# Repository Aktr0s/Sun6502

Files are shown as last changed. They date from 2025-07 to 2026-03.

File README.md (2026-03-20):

# Sun6502 Hobby Computer

## My first try at electonics. Wish me luck.

# Memory Map:

| Address Range | Size | Description |
|---|---|---|
| `$0000-$7FFF` | 32KB | RAM |
| `$8000-$83FF` | 1KB | VIA #1 |
| `$8400-$87FF` | 1KB | UART |
| `$8800-$8BFF` | 1KB | VIA #2 |
| `$8C00-$8FFF` | 1KB | Unused |
| `$9000-$BFFF` | 12KB | Expansion Port |
| `$C000-$FFFF` | 16KB | ROM |

> **Total:** 64KB

> **If you have a previous version of the board notice that UART and VIA #2 addresses are swaped around.**

## More Info:
While VIA's and UART have 1KB they only use first needed bits.

VIA#2 Port (Expansion) does not have CE/ signal but Bus Expansion Port does.

It should be compatible with Ben's Breadboard 6502 but you **HAVE** to change memory adressess since the memory map is different as well as elements connected to VIA

### The project took inspiration from:
* Ben Eater Breadboard 6502 Computer
* PE6502 by Putnam Electronics

> [!NOTE]
> This project has been tested and is confirmed to work.

> [!CAUTION]
> Do NOT use 74LS series TTL chips. It messes up logic and memory.
> Use 74HC series CMOS chips! If somewhere on PCB or schematic there is a mention of TTL chips, ignore them and use CMOS chips!

## Software:

Software for this computer is based on 
* [msbasic](https://github.com/mist64/msbasic), licensed under the 2-clause BSD license.

* As well as it's modified version by [Ben Eater](https://github.com/beneater/msbasic).

Original README files are in "msbasic_for_sun6502" folder.

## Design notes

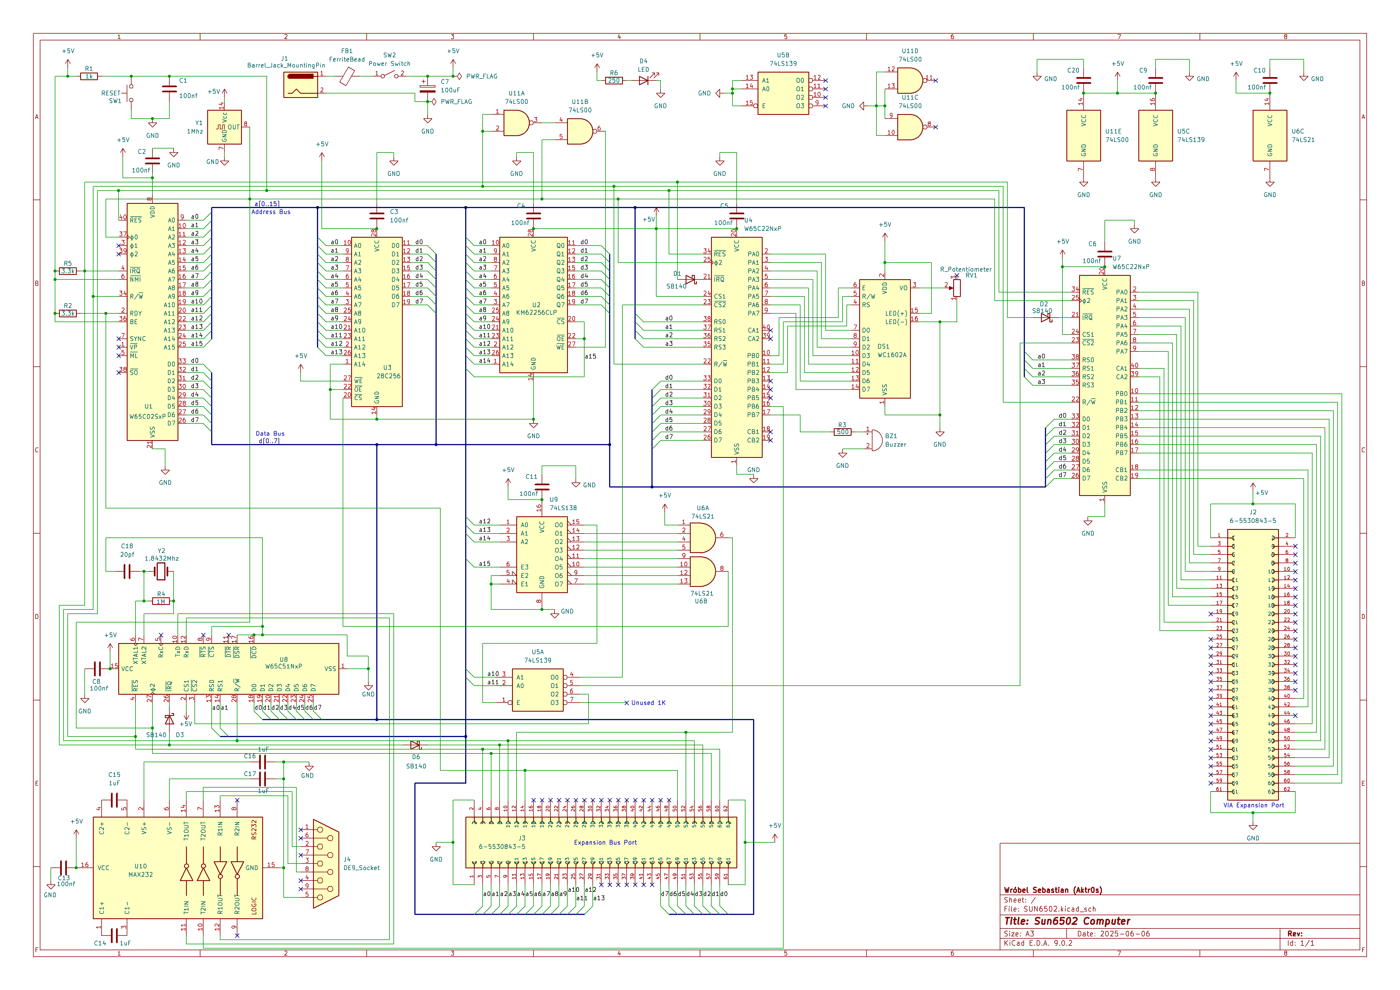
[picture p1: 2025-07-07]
schematic.png

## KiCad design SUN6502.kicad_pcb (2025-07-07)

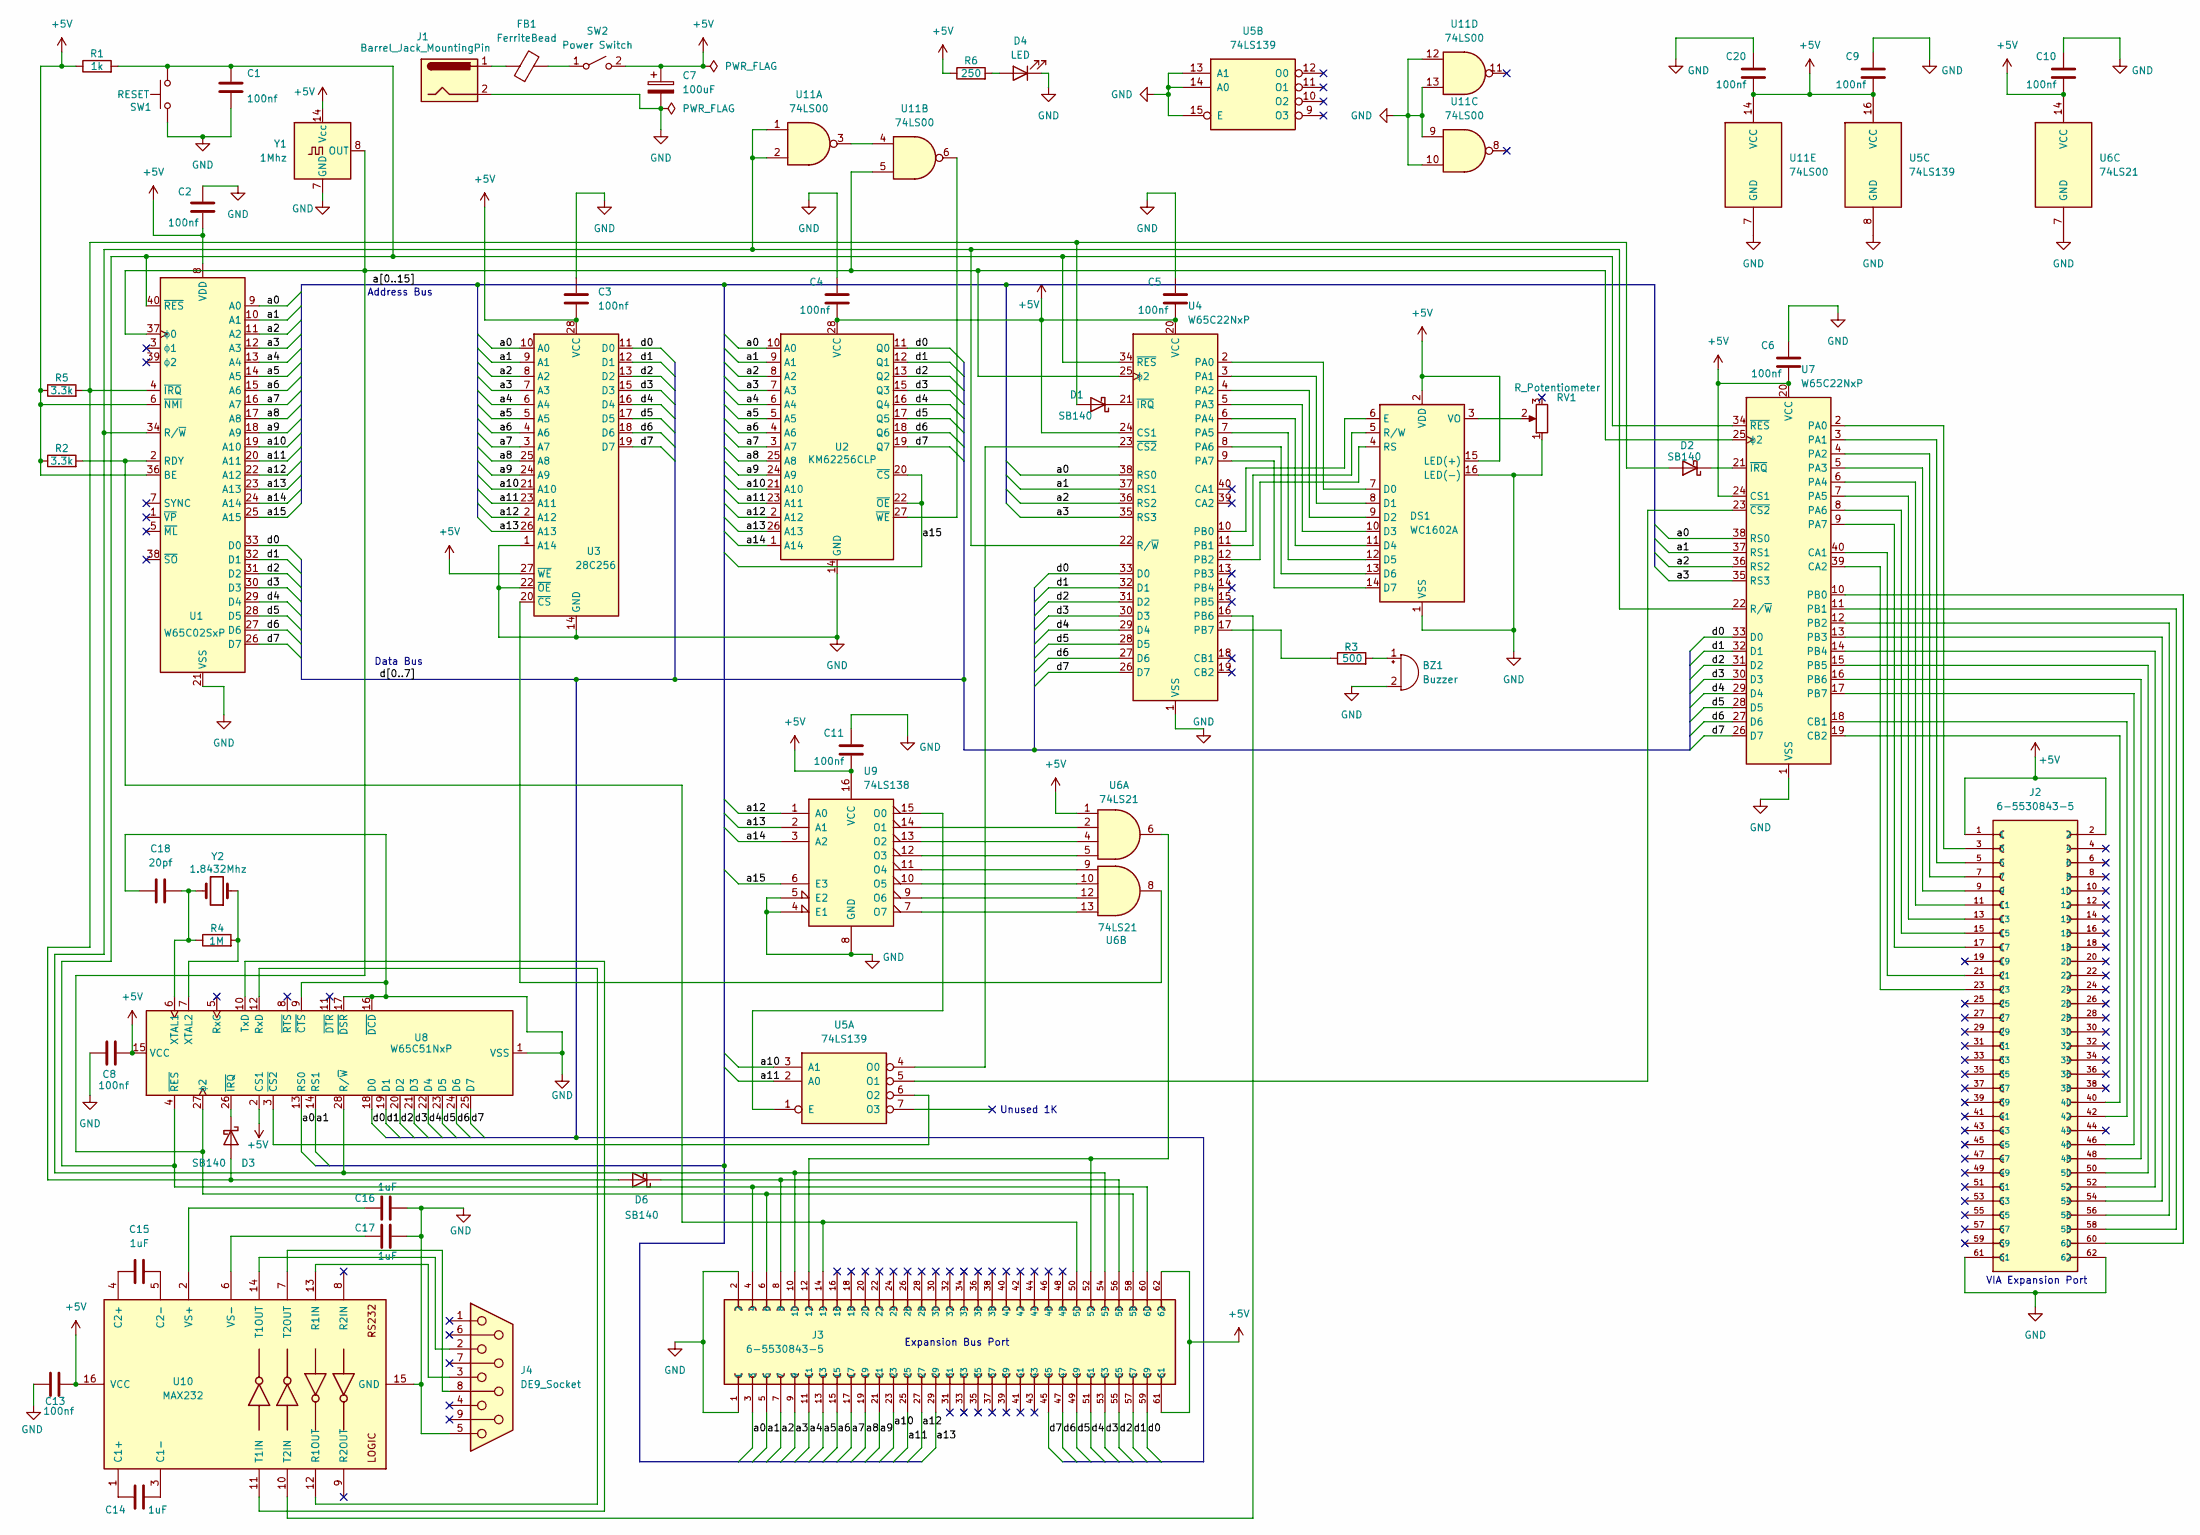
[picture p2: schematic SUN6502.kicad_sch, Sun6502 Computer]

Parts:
BZ1: Buzzer; Buzzer_TDK_PS1240P02BT_D12.2mm_H6.5mm
C1, C2, C3, C4, C5, C6, C8, C9, C10, C11, C13: 100nf; C_Disc_D5.0mm_W2.5mm_P5.00mm
C7: 100uF; CP_Radial_D6.3mm_P2.50mm
C14, C15, C16, C17: 1uF; C_Disc_D5.0mm_W2.5mm_P5.00mm
C18: 20pf; C_Disc_D5.0mm_W2.5mm_P5.00mm
C20: 100nf; C_Disc_D4.7mm_W2.5mm_P5.00mm
D1, D2, D3, D6: SB140; D_DO-41_SOD81_P10.16mm_Horizontal
D4: LED; LED_D5.0mm
DS1: WC1602A
FB1: FerriteBead; LairdTech_28C0236-0JW-10
J1: Barrel_Jack_MountingPin; BarrelJack_Horizontal
J2, J3: 6-5530843-5; TE_6-5530843-5
J4: DE9_Socket; DSUB-9_Socket_Horizontal_P2.77x2.84mm_EdgePinOffset7.70mm_H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
R1: 1k; R_Axial_DIN0207_L6.3mm_D2.5mm_P15.24mm_Horizontal
R2, R5: 3.3k; R_Axial_DIN0207_L6.3mm_D2.5mm_P15.24mm_Horizontal
R3: 500; R_Axial_DIN0207_L6.3mm_D2.5mm_P15.24mm_Horizontal
R4: 1M; R_Axial_DIN0207_L6.3mm_D2.5mm_P15.24mm_Horizontal
R6: 250; R_Axial_DIN0207_L6.3mm_D2.5mm_P10.16mm_Horizontal
RV1: R_Potentiometer; Potentiometer_Alps_RK09K_Single_Vertical
SW1: RESET; SW_PUSH_6mm_H5mm
SW2: Power Switch; 2MS6T1B3M2QES
U1: W65C02SxP; DIP-40_W15.24mm_Socket_LongPads
U2: KM62256CLP; DIP-28_W15.24mm_Socket_LongPads
U3: 28C256; DIP_Socket-28_W11.9_W12.7_W15.24_W17.78_W18.5_3M_228-1277-0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
U4, U7: W65C22NxP; DIP-40_W15.24mm_Socket_LongPads
U5: 74LS139; DIP-16_W7.62mm_Socket_LongPads
U6: 74LS21; DIP-14_W7.62mm_Socket_LongPads
U8: W65C51NxP; DIP-28_W15.24mm_Socket_LongPads
U9: 74LS138; DIP-16_W7.62mm_Socket_LongPads
U10: MAX232; DIP-16_W7.62mm_Socket_LongPads
U11: 74LS00; DIP-14_W7.62mm_Socket_LongPads
Y1: 1Mhz; Oscillator_DIP-14
Y2: 1.8432Mhz; Crystal_HC49-U_Vertical

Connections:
+5V: C2.2, C3.2, C4.2, C5.2, C6.2, C7.1, C8.2, C9.2, C10.2, C11.2, C13.2, C20.2, DS1.2 (VDD), DS1.15 (LED(+)), J2.1, J2.2, J3.61, J3.62, R1.1, R2.1, R5.1, R6.1, SW2.2 (B), U1.6 (~NMI), U1.8 (VDD), U1.36 (BE), U2.28 (VCC), U3.27 (~WE), U3.28 (VCC), U4.20 (VCC), U4.24 (CS1), U5.16 (VCC), U6.1, U6.14 (VCC), U7.20 (VCC), U7.24 (CS1), U8.2 (CS1), U8.15 (VCC), U9.16 (VCC), U10.16 (VCC), U11.14 (VCC), Y1.14 (Vcc)
/a0: J3.3, U1.9 (A0), U2.10 (A0), U3.10 (A0), U4.38 (RS0), U7.38 (RS0), U8.13 (RS0)
/a1: J3.5, U1.10 (A1), U2.9 (A1), U3.9 (A1), U4.37 (RS1), U7.37 (RS1), U8.14 (RS1)
/a2: J3.7, U1.11 (A2), U2.8 (A2), U3.8 (A2), U4.36 (RS2), U7.36 (RS2)
/a3: J3.9, U1.12 (A3), U2.7 (A3), U3.7 (A3), U4.35 (RS3), U7.35 (RS3)
/a4: J3.11, U1.13 (A4), U2.6 (A4), U3.6 (A4)
/a5: J3.13, U1.14 (A5), U2.5 (A5), U3.5 (A5)
/a6: J3.15, U1.15 (A6), U2.4 (A6), U3.4 (A6)
/a7: J3.17, U1.16 (A7), U2.3 (A7), U3.3 (A7)
/a8: J3.19, U1.17 (A8), U2.25 (A8), U3.25 (A8)
/a9: J3.21, U1.18 (A9), U2.24 (A9), U3.24 (A9)
/a10: J3.23, U1.19 (A10), U2.21 (A10), U3.21 (A10), U5.3 (A1)
/a11: J3.25, U1.20 (A11), U2.23 (A11), U3.23 (A11), U5.2 (A0)
/a12: J3.27, U1.22 (A12), U2.2 (A12), U3.2 (A12), U9.1 (A0)
/a13: J3.29, U1.23 (A13), U2.26 (A13), U3.26 (A13), U9.2 (A1)
/a14: U1.24 (A14), U2.1 (A14), U9.3 (A2)
/a15: U1.25 (A15), U2.20 (~CS), U2.22 (~OE), U9.6 (E3)
/d0: J3.59, U1.33 (D0), U2.11 (Q0), U3.11 (D0), U4.33 (D0), U7.33 (D0), U8.18 (D0)
/d1: J3.57, U1.32 (D1), U2.12 (Q1), U3.12 (D1), U4.32 (D1), U7.32 (D1), U8.19 (D1)
/d2: J3.55, U1.31 (D2), U2.13 (Q2), U3.13 (D2), U4.31 (D2), U7.31 (D2), U8.20 (D2)
/d3: J3.53, U1.30 (D3), U2.15 (Q3), U3.15 (D3), U4.30 (D3), U7.30 (D3), U8.21 (D3)
/d4: J3.51, U1.29 (D4), U2.16 (Q4), U3.16 (D4), U4.29 (D4), U7.29 (D4), U8.22 (D4)
/d5: J3.49, U1.28 (D5), U2.17 (Q5), U3.17 (D5), U4.28 (D5), U7.28 (D5), U8.23 (D5)
/d6: J3.47, U1.27 (D6), U2.18 (Q6), U3.18 (D6), U4.27 (D6), U7.27 (D6), U8.24 (D6)
/d7: J3.45, U1.26 (D7), U2.19 (Q7), U3.19 (D7), U4.26 (D7), U7.26 (D7), U8.25 (D7)
GND: BZ1.2 (-), C1.2, C2.1, C3.1, C4.1, C5.1, C6.1, C7.2, C8.1, C9.1, C10.1, C11.1, C13.1, C16.2, C17.2, C18.1, C20.1, D4.1 (K), DS1.1 (VSS), DS1.16 (LED(-)), J1.2, J2.61, J2.62, J3.1, J3.2, J4.5, RV1.1, SW1.1, U1.21 (VSS), U2.14 (GND), U3.1 (A14), U3.14 (GND), U3.22 (~OE), U4.1 (VSS), U5.8 (GND), U5.13 (A1), U5.14 (A0), U5.15 (E), U6.7 (GND), U7.1 (VSS), U8.1 (VSS), U8.9 (~CTS), U8.16 (~DCD), U8.17 (~DSR), U9.4 (E1), U9.5 (E2), U9.8 (GND), U10.15 (GND), U11.7 (GND), U11.9, U11.10, U11.12, U11.13, Y1.7 (GND)
unnamed: BZ1.1 (+), R3.2
unnamed: D1.2 (A), D2.2 (A), D3.2 (A), D6.2 (A), R5.2, U1.4 (~IRQ)
unnamed: D1.1 (K), U4.21 (~IRQ)
unnamed: D2.1 (K), U7.21 (~IRQ)
unnamed: D3.1 (K), U8.26 (~IRQ)
unnamed: D4.2 (A), R6.2
unnamed: D6.1 (K), J3.8, J3.56
unnamed: DS1.7 (D0), U4.2 (PA0)
unnamed: DS1.8 (D1), U4.3 (PA1)
unnamed: DS1.9 (D2), U4.4 (PA2)
unnamed: DS1.10 (D3), U4.5 (PA3)
unnamed: DS1.11 (D4), U4.6 (PA4)
unnamed: DS1.12 (D5), U4.7 (PA5)
unnamed: DS1.13 (D6), U4.8 (PA6)
unnamed: DS1.14 (D7), U4.9 (PA7)
unnamed: DS1.6 (E), U4.10 (PB0)
unnamed: DS1.4 (RS), U4.12 (PB2)
unnamed: DS1.5 (R/W), U4.11 (PB1)
unnamed: DS1.3 (VO), RV1.2
unnamed: FB1.1, J1.1
unnamed: J3.12, J3.52, U6.6
unnamed: FB1.2, SW2.1 (A)
unnamed: J3.14, J3.50, R2.2, U1.2 (RDY)
unnamed: J3.10, J3.54, U1.34 (R/~W), U4.22 (R/~W), U7.22 (R/~W), U8.28 (R/~W), U11.1, U11.2
unnamed: C1.1, J3.4, J3.60, R1.2, SW1.2, U1.40 (~RES), U4.34 (~RES), U7.34 (~RES), U8.4 (~RES)
unnamed: J3.6, J3.58, U1.37 (ϕ0), U4.25 (ϕ2), U7.25 (ϕ2), U8.27 (ϕ2), U11.5, Y1.8 (OUT)
unnamed: U2.27 (~WE), U11.6
unnamed: U3.20 (~CS), U6.8
unnamed: R3.1, U4.17 (PB7)
unnamed: U4.23 (~CS2), U5.4 (O0)
unnamed: U5.1 (E), U9.15 (O0)
unnamed: U5.5 (O1), U7.23 (~CS2)
unnamed: U5.6 (O2), U8.3 (~CS2)
unnamed: J2.21, U7.40 (CA1)
unnamed: J2.23, U7.39 (CA2)
unnamed: J2.42, U7.18 (CB1)
unnamed: J2.40, U7.19 (CB2)
unnamed: J2.3, U7.2 (PA0)
unnamed: J2.5, U7.3 (PA1)
unnamed: J2.7, U7.4 (PA2)
unnamed: J2.9, U7.5 (PA3)
unnamed: J2.11, U7.6 (PA4)
unnamed: J2.13, U7.7 (PA5)
unnamed: J2.15, U7.8 (PA6)
unnamed: J2.17, U7.9 (PA7)
unnamed: J2.60, U7.10 (PB0)
unnamed: J2.58, U7.11 (PB1)
unnamed: J2.56, U7.12 (PB2)
unnamed: J2.54, U7.13 (PB3)
unnamed: J2.52, U7.14 (PB4)
unnamed: J2.50, U7.15 (PB5)
unnamed: J2.48, U7.16 (PB6)
unnamed: J2.46, U7.17 (PB7)
unnamed: C18.2, R4.1, U8.6 (XTAL1), Y2.2
unnamed: R4.2, U8.7 (XTAL2), Y2.1
unnamed: U6.2, U9.14 (O1)
unnamed: U6.4, U9.13 (O2)
unnamed: U6.5, U9.12 (O3)
unnamed: U6.9, U9.11 (O4)
unnamed: U6.10, U9.10 (O5)
unnamed: U6.12, U9.9 (O6)
unnamed: U6.13, U9.7 (O7)
unnamed: C14.1, U10.1 (C1+)
unnamed: C14.2, U10.3 (C1-)
unnamed: C15.1, U10.4 (C2+)
unnamed: C15.2, U10.5 (C2-)
unnamed: J4.3, U10.13 (R1IN)
unnamed: U8.12 (RxD), U10.12 (R1OUT)
unnamed: U8.10 (TxD), U10.11 (T1IN)
unnamed: J4.2, U10.14 (T1OUT)
unnamed: U4.16 (PB6), U10.10 (T2IN)
unnamed: J4.8, U10.7 (T2OUT)
unnamed: C16.1, U10.2 (VS+)
unnamed: C17.1, U10.6 (VS-)
unnamed: U11.3, U11.4

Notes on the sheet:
Unused 1K
Address Bus
VIA Expansion Port
Expansion Bus Port
Data Bus

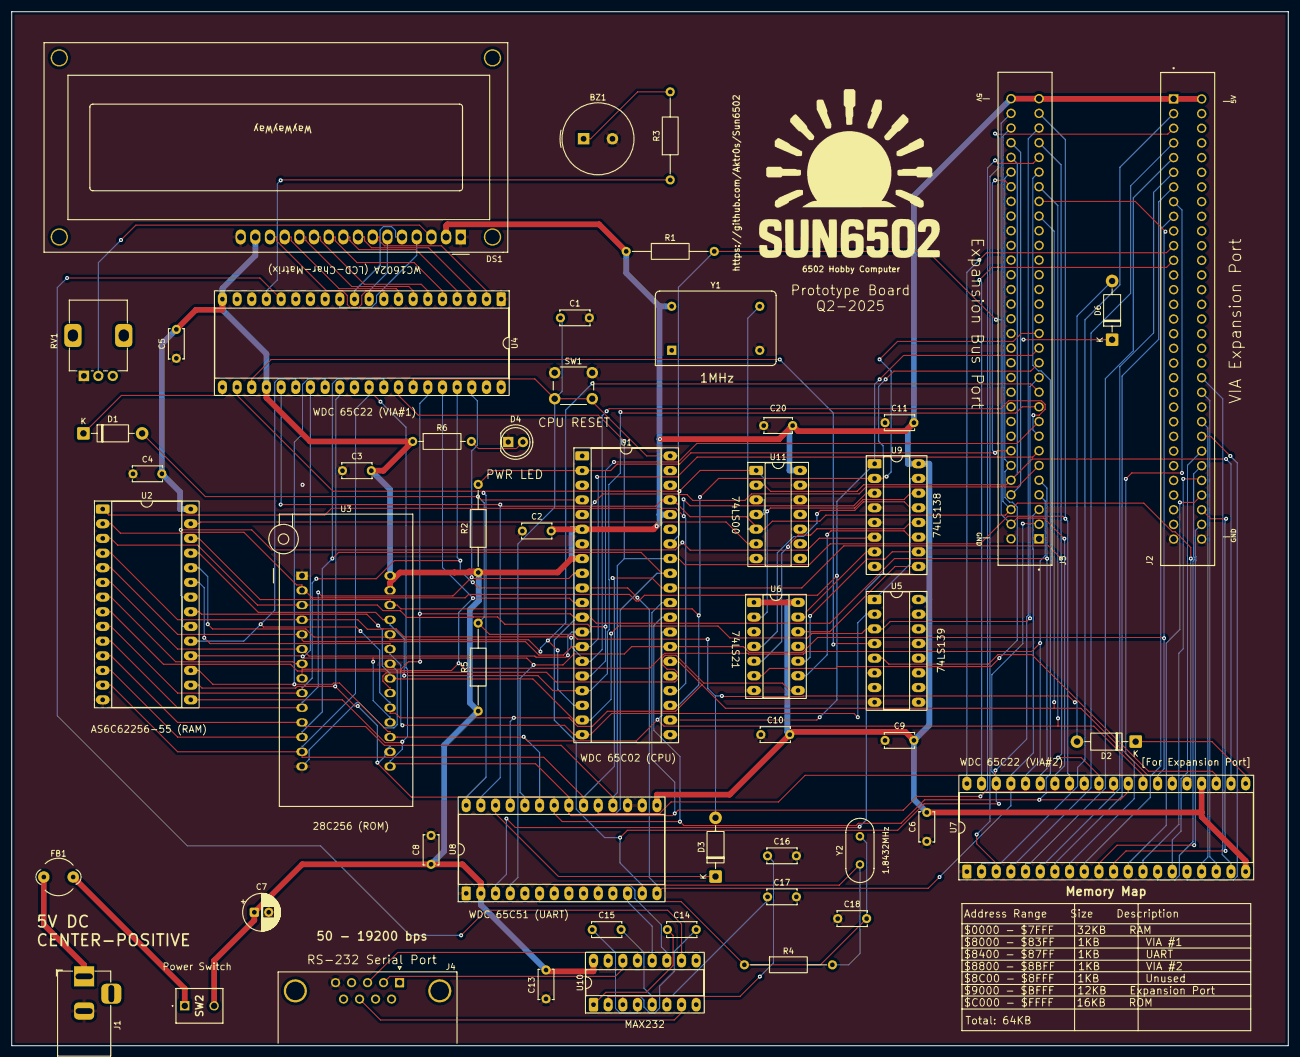
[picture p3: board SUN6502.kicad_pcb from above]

Board: 2 copper layers, 221.0 x 179.0 mm, 52 parts (0 on the bottom side), 101 nets.

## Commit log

2025-05-27 inicial commit
    [SUN6502.kicad_pcb, SUN6502.kicad_sch]
2025-06-02 updates, removed backup files
    [SUN6502.kicad_sch]
2025-06-06 updates, schematic more or less ready for pcb mapping
    [SUN6502.kicad_sch]
2025-06-08 pcb layout done
    [SUN6502.kicad_pcb, SUN6502.kicad_sch]
2025-06-11 updates, changed ROM socket into ZIF
    [SUN6502.kicad_pcb, SUN6502.kicad_sch]
2025-06-13 pcb changed to 2 layers, CTR Added
    [SUN6502.kicad_pcb, SUN6502.kicad_sch]
2025-06-17 small changes
    [SUN6502.kicad_pcb, SUN6502.kicad_sch]
2025-07-07 updates, board works
    [SUN6502.kicad_pcb, SUN6502.kicad_sch, eater.cfg]
2026-06-10 fixes, changed intro message and prompt. changed defines from eater to sun6502
    [sun6502.cfg]
